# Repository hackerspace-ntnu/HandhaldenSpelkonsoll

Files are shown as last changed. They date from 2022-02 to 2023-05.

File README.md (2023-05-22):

# Handhalden Spelkonsoll
  
Dette er et prosjekt med mål om å utvikle en håndholdt spillkonsoll basert på ESP32 og skjermkontrolleren ILI9488.  
Spillkonsollen kommer med et egetutviklet snake-spill.
  
# Features som er planlagt og i utvikling:  
#### Hardware:  
* mikrokontroller: ESP32 dev board
* skjerm: ILI9488 480*320, 3.5"  
* input: Dpad + 4 knapper
* kretskort: [custom KiCad modell](hardware/kretskort/)  
* kabinett: 3d printet, [cad filer](hardware/design/) følger og det er åpent for tilpassing som i valg av farger

#### Software:  
* Spill: snake  
* Grafikk: [LVGL](https://github.com/lvgl/lvgl)
* ~~Kommunikasjonsprotokoll: [ESP-NOW](https://github.com/espressif/esp-now)~~

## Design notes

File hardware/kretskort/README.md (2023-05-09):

# kretskort

## TODO
- [ ] Fikse pull-up/down resistor (ikke ha en wack kombo av begge)
- [ ] Snu ESP-en, så usben ikke krasjer med resistorene
- [ ] Fjerne de knappene vi ikke trenger/ikke kan ha, pin 5-12 var muligens problematisk, flere kan også være det
- [ ] Finne riktige pins til skjermen
- [ ] Route på nytt

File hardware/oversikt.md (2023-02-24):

## Hardware (endringer kan forekomme)
* MCU: ESP32 
* Skjerm: ILI9488 480*320, 3.5"
* Knapper: Dpad + 4  
* Batteri: 18650 Li-ion (3.6 V, 2600 mAh)

## Koblinger mellom ILI9488 og ESP32
|ILI9488 | ESP32 | Notes: |
|---|---|---|
| SDO(MISO) |  19 | Master In Slave Out|
| SDO(MOSI) |  23 | Master out Slave In|
| SCK |  18 | Clock Signal | 
| CS |  16 | Chip Select |
| DC/RS |  17 | Data Command | 
| RST | 4 | Reset |
| VCC |  5V | Or 3.3V |
| LED |  5V | Or 3.3V |
| GND |  GND  | Ground |

## Koblinger mellom knapper og ESP32
| Knapp | ESP32 |
|---|---|
| BTN_A |  21 | 
| BTN_B |  32 |
| BTN_X |  33 |
| BTN_Y |  25 |
| BTN_DP_LEFT  |  14 | 
| BTN_DP_RIGHT |  13 | 
| BTN_DP_UP |  26 | 
| BTN_DP_DOWN  |  27 |

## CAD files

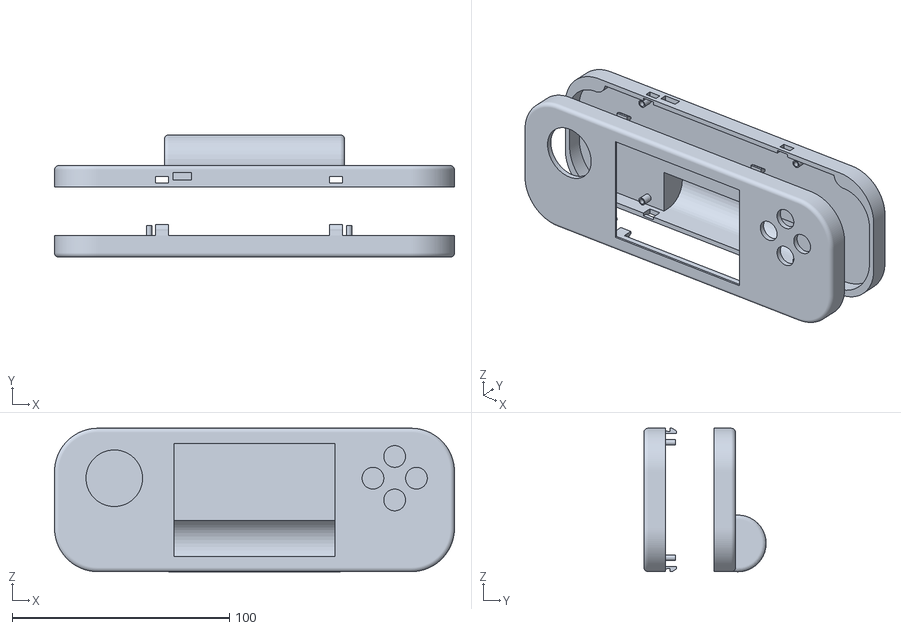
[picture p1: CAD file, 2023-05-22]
hardware/design/spillkonsoll_case.stl
184.0 x 56.3 x 66.0

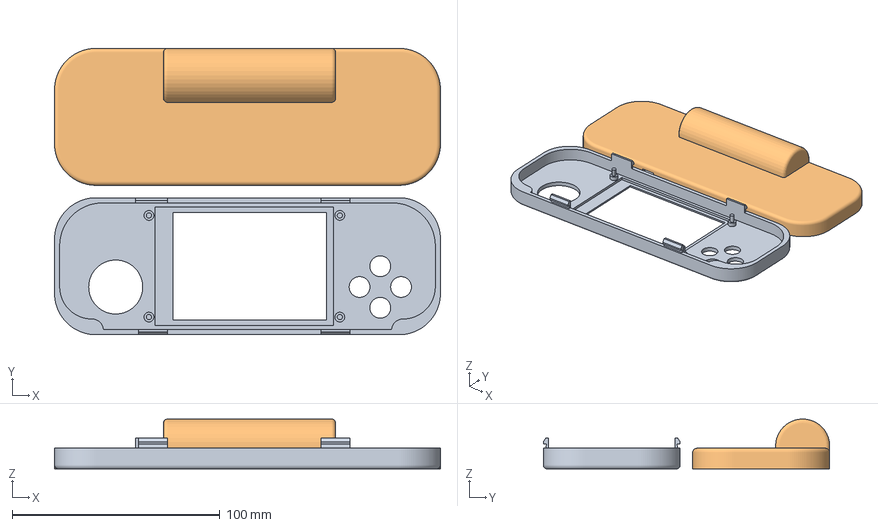
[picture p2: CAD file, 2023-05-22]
hardware/design/spillkonsoll_case_v3.3mf
186.0 x 138.0 x 24.1 mm
spillkonsoll_case_v3.stl_1
spillkonsoll_case_v3.stl_2

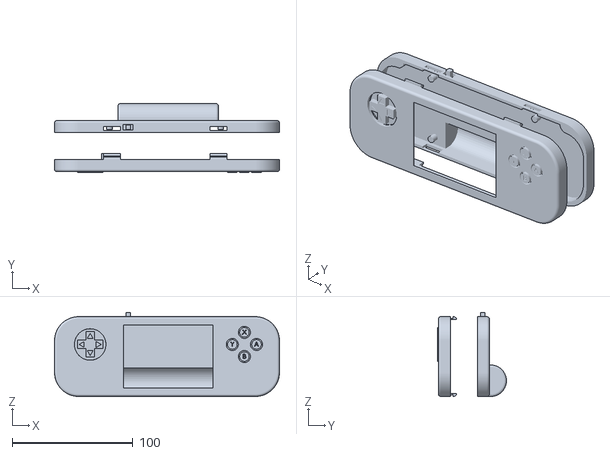
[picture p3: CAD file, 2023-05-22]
hardware/design/spillkonsoll_case_buttons.stl
186.0 x 57.0 x 69.5

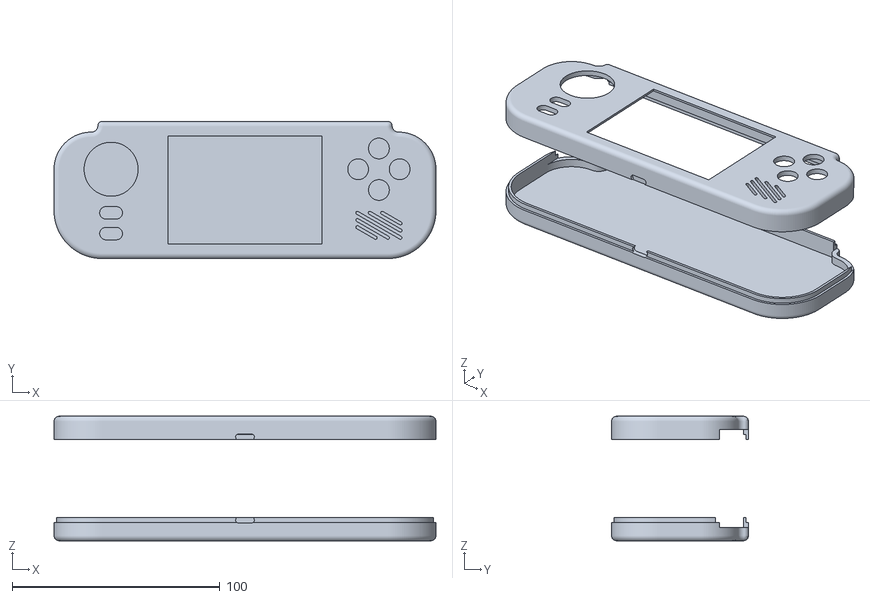
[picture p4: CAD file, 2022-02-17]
hardware/design/HandhaldenSpelkonsoll_1-1-3.stl
184.0 x 66.0 x 60.0

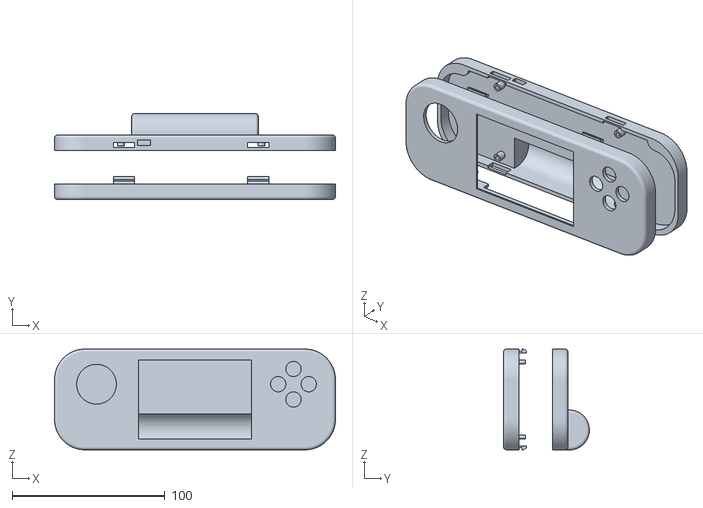
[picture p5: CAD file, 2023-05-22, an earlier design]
hardware/design/spillkonsoll_case_v2.stl
184.0 x 56.3 x 66.0

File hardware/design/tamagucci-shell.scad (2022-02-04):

// import("file.svg");

frontShell();

module frontShell() {
    difference() {
        frontShellWithoutHoles();
        frontHoles();
    }
}



module frontShellWithoutHoles() {
    difference() {
        union(){
            linear_extrude(15){
                translate([0, 0, 0]) {
                    square(size=[150, 70], center=true);
                }
            }
        }
        v = 2; 
        union(){
            translate([v/2, v/2, 0.1]) {
            linear_extrude(15){
                    square(size=[150-v*2, 70-v*2], center=true);
                }
            }
        }
    }
}

module frontHoles() {
    translate([0, 0, -0.1]) {
        linear_extrude(10){
            color([0/255, 0/255, 0/255]) {
                dpadHole(60,15);
                ssButtonHole(60,-20);
                gameButtonHole(-60,10);
                speakerHoles(-60,-20);
                screenHole();
            }
        }
    }
}

module hsLogo(x,y) {
    translate([x, y, 0]) {
        linear_extrude(height=10, center=true, convexity=10, twist=0) {
        import("Icon_green_transparent.svg");
        }
    }
}

module dpadHole(xPos,yPos) {
    d = 20;    //not acurate number 
    
    translate([xPos, yPos, 0]) {
        circle(r=d/2);
    }
}

module ssButtonHole(x,y) {

    x = x-2; //just to prettify. is bad code.

    d=6;  //depth
    w=10;  //heigth

    xDist = 0; // dist between buttons.
    yDist = 8;

    translate([x, y, 0]) {
        union(){
            circle(r=d/2, $fn=20);
            translate([w-d, 0, 0]) {
                circle(r=d/2, $fn=20);
            }
            translate([w/2 - d/2, 0, 0]) {
                square(size=[w-d, d], center=true);
            }
        }
    }
    translate([x+xDist, y+yDist, 0]) {
        union(){
            circle(r=d/2, $fn=20);
            translate([w-d, 0, 0]) {
                circle(r=d/2, $fn=20);
            }
            translate([w/2 - d/2, 0, 0]) {
                square(size=[w-d, d], center=true);
            }
        }
    }



}

module speakerHoles(xPos,yPos) {

    d=1; //diameter of lines
    l = 20; //mex length of diagonale in lines
    r = 37; //positive verdier.

    
    translate([xPos, yPos, 0]) {

        rotate([0, 0, r]) {
            union(){
                
                speakerHOleLine(d,l);
                //not geometrically parametric
                per = 0.7;
                translate([-cos(r), sin(r)+2*d, 0]) 
                    speakerHOleLine(d,l*per);
                translate([+cos(r), -sin(r)-2*d, 0]) 
                    speakerHOleLine(d,l*per);
                per2 = 0.4;
                translate([-2*cos(r), 2*sin(r)+4*d, 0]) 
                    speakerHOleLine(d,l*per2);
                translate([2*cos(r), -2*sin(r)-4*d, 0]) 
                    speakerHOleLine(d,l*per2);
                

            }
        }
    }
}
module speakerHOleLine(d,l) {
        union(){
            translate([(-l+d)/2, 0, 0]) {
            circle(r=d/2, $fn=15);
            }
            translate([(l-d)/2, 0, 0]) {
                circle(r=d/2, $fn=15);
            }
            square(size=[l-d, d], center=true);
        }
    
}



module gameButtonHole(xPos,yPos) {
    d = 10;     //not acurate number //diameter

    xDist = 15;  //not acurate number
    yDist = 20;  //not acurate number

    res = 30; //resolution of circle (polygon count)

    // translate([xPos, yPos, 0]) {
    //     circle(r=2); //centre pos
    // }
    translate([xPos+xDist/2, yPos, 0]) {
        circle(r=d/2 , $fn=res); //a
    }
    translate([xPos-xDist/2, yPos, 0]) {
        circle(r=d/2 , $fn=res); //y
    }
    translate([xPos, yPos+yDist/2, 0]) {
        circle(r=d/2 , $fn=res); //x
    }
    translate([xPos, yPos-yDist/2, 0]) {
        circle(r=d/2 , $fn=res); //b
    }
}

module screenHole() {
    wScreen = 85;
    hScreen = 56;
    //skjerm
    square(size=[wScreen, hScreen], center=true);
}

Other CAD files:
hardware/design/knapper.blend
hardware/design/spillkonsoll_case.blend
hardware/design/spillkonsoll_case_old.blend
hardware/design/spillkonsoll_case_v3.stl

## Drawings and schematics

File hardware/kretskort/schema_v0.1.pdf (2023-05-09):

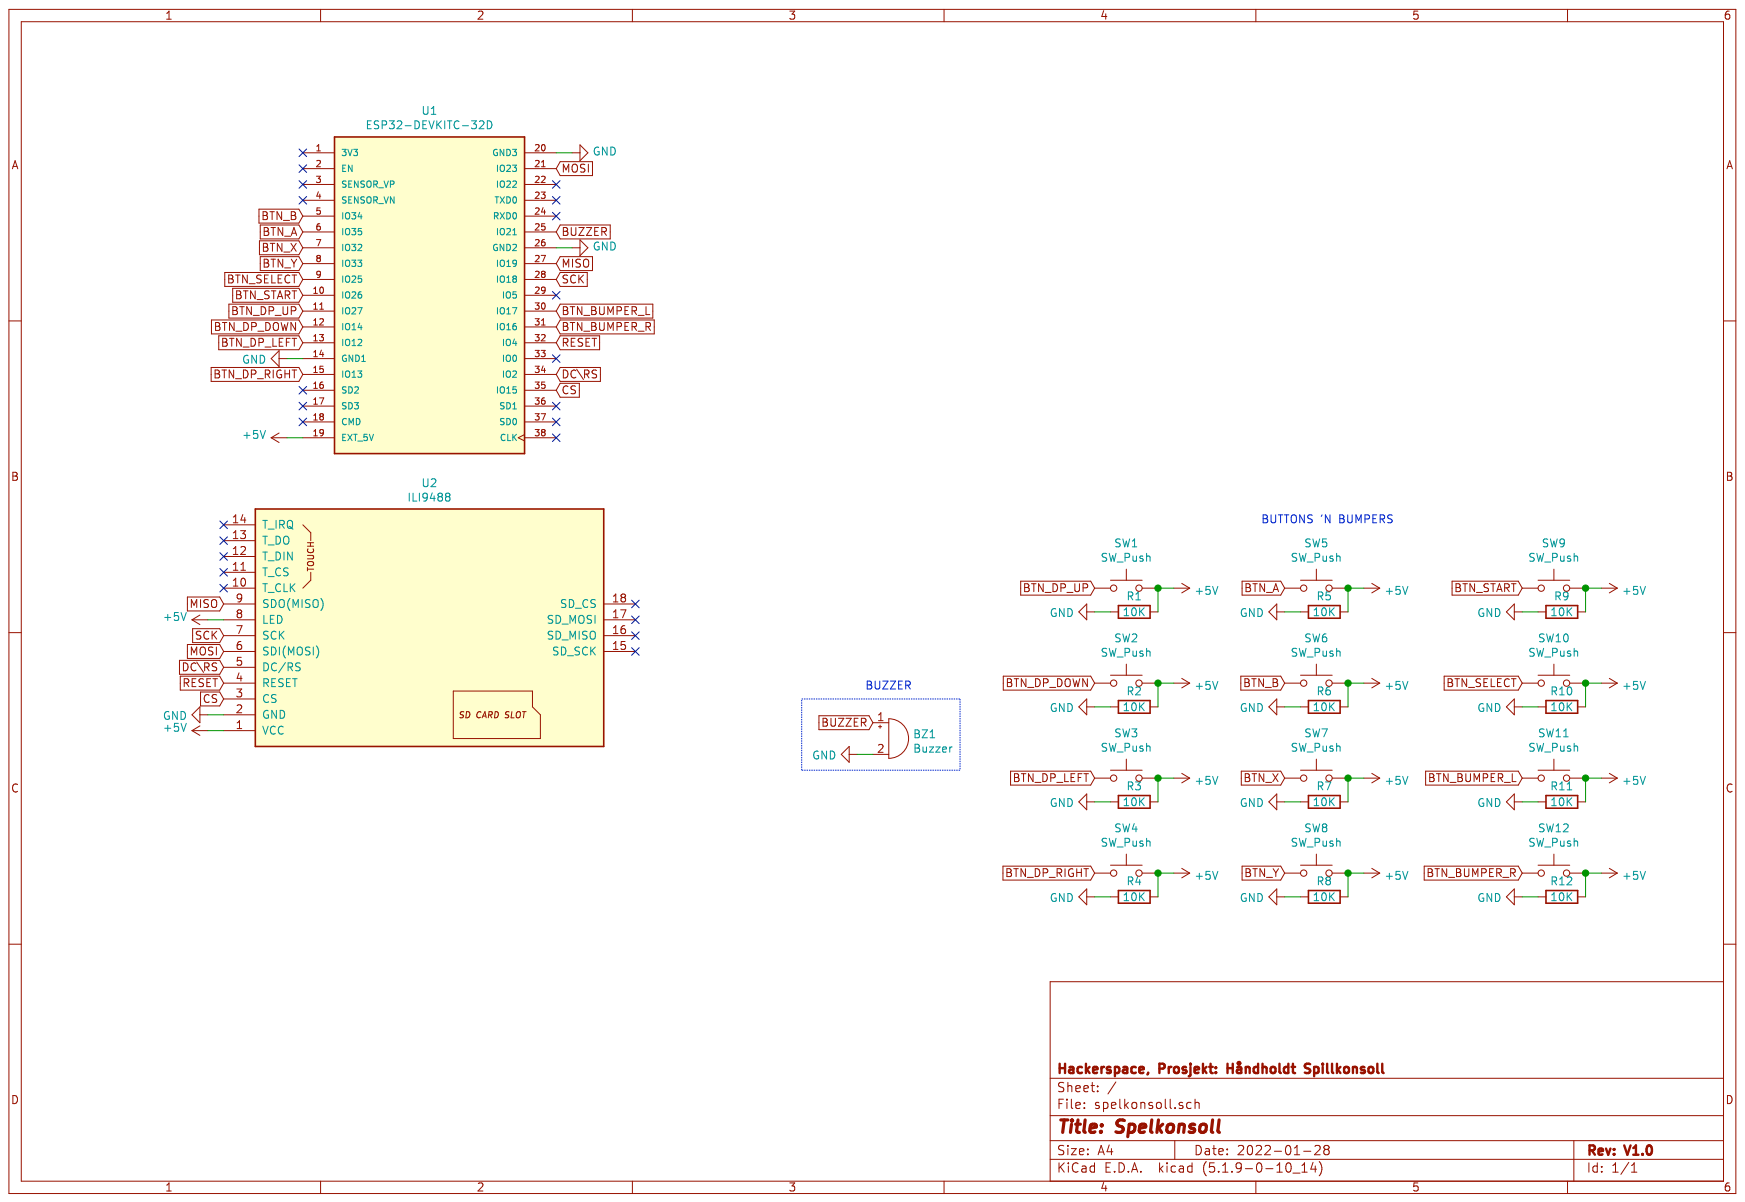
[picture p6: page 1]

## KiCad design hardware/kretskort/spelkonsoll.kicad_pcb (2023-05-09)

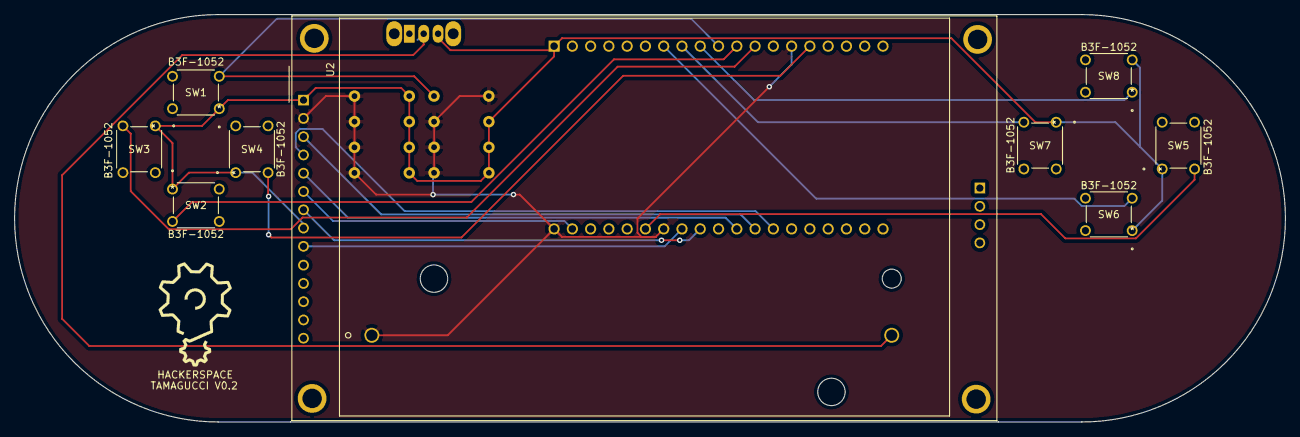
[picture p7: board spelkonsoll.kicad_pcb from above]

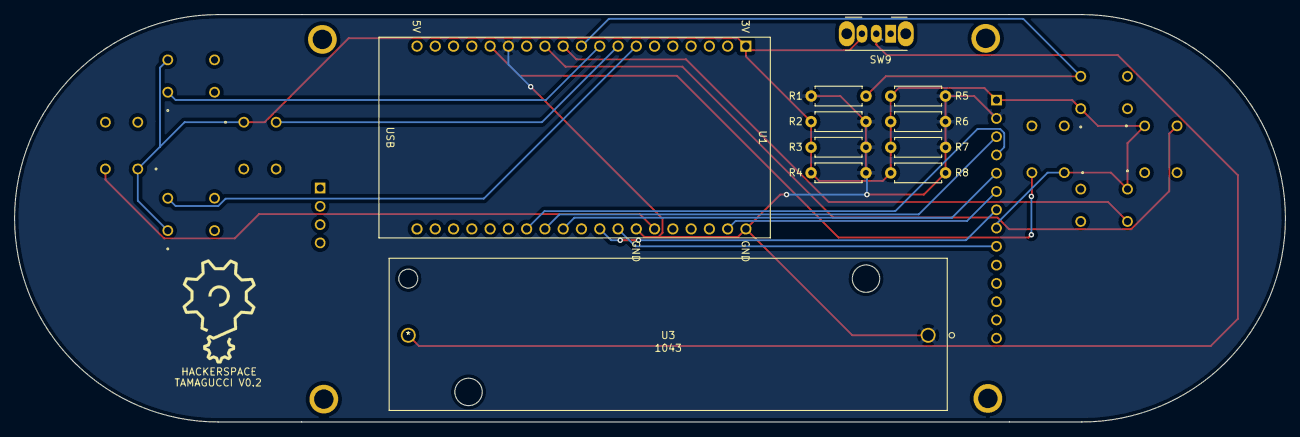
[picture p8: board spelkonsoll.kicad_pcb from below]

Board: 2 copper layers, 176.6 x 56.6 mm, 20 parts (11 on the bottom side), 17 nets.

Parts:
R1, R2, R3, R4, R5, R6, R7, R8: 10K; R_Axial_DIN0207_L6.3mm_D2.5mm_P7.62mm_Horizontal
SW1, SW2, SW3, SW4, SW5, SW6, SW7, SW8: B3F-1052; Button
SW9: SW_DPDT_x2; PowerButton
U1: ESP32-DEVKITC-32D; MODULE_ESP32-DEVKITC-32D
U2: ILI9488
U3: 1043; 18650holder

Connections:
+5V: R2.1, R3.1, R4.1, R5.1, R6.1, R7.1, R8.1, SW1.1, SW2.1, SW3.1, SW4.1, SW5.1, SW6.1, SW7.1, SW8.3, SW9.3, U1.1, U2.1, U2.8
BTN_A: SW5.3, U1.25
BTN_B: SW6.3, U1.7
BTN_DP_DOWN: SW2.3, U1.11
BTN_DP_LEFT: SW3.3, U1.12
BTN_DP_RIGHT: SW4.3, U1.15
BTN_DP_UP: R1.1, SW1.3, U1.10
BTN_X: SW7.3, U1.8
BTN_Y: SW8.1, U1.9
CS: U1.31, U2.3
DC\RS: U1.30, U2.5
GND: R1.2, R2.2, R3.2, R4.2, R5.2, R6.2, R7.2, R8.2, U1.14, U1.20, U1.26, U2.2, U3.1
MISO: U1.27, U2.9
MOSI: U1.21, U2.6
unnamed: SW9.2, U3.2
RESET: U1.32, U2.4
SCK: U1.28, U2.7

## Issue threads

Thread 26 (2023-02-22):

Memory error in create_snake

Joakim-droid, 2023-02-22:
During a graphics-test, I discovered that when creating a snake the ESP32 keeps resetting itself because of a memory-error. Following the stack-trace the problem occurs at line 10 and 13 in push() in snake.c, where memory is allocated for the new part and new coordinates is set. I suspect the coordinates is wrong somehow, but it could also be that it fails to allocate memory.

Joakim-droid, 2023-04-22:
Fixed

Closed 2023-04-22.

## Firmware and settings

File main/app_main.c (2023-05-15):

#include "board.h"
#include "snake.h"
#include "button.h"
#include "lvgl.h"
#include "lvgl_helpers.h"
#include "esp_freertos_hooks.h"
#include "freertos/semphr.h"
#include "esp_system.h"
#include "esp_timer.h"
#include "esp_heap_caps.h"
#include "driver/gpio.h"


#define LV_TICK_PERIOD_MS 1

board_piece_t* p_board;
snake_t test_snake;
int tick = 0;
int snake_count = 0;
int food_count=0;



lv_obj_t* brd_lv_obj_t[BOARD_HEIGHT*BOARD_WIDTH];
lv_obj_t* bkgrnd;
lv_obj_t* block_food;

static board_piece_t board[BOARD_HEIGHT * BOARD_WIDTH];
board_piece_t* p_board = &board[0];

static void lv_tick_task(void *arg);
static void guiTask(void *pvParameter);
void draw_board(board_piece_t* p);

lv_color_t* buf1;
lv_color_t* buf2;
SemaphoreHandle_t xGuiSemaphore;
int direction=0;

gpio_num_t button_pins[4] = {BTN_DP_UP, BTN_B, BTN_DP_RIGHT,BTN_A};

lv_style_t style_snake;
lv_style_t style_blank;
lv_style_t style_food;

void init_buttons() {
    for(int i=0; i<4; i++){
        gpio_set_direction(button_pins[i], GPIO_MODE_INPUT);
    }
}

int read_button(gpio_num_t pin) {
    return gpio_get_level(pin);
}

void app_main(void){

    int tick = 0;
    int count_food = 0;
    int do_movement = 1;
    int snake_id_counter = 0;
    
    init_buttons();

    snake_t snake1;
    snake_t snake2;

    int init_coordinates1[][2] = {{0, 0}, {1, 0}, {2, 0}}; 
    int init_coordinates2[][2] = {{BOARD_WIDTH-0, BOARD_HEIGHT-1}, {BOARD_WIDTH-2, BOARD_HEIGHT-1}, {BOARD_WIDTH-3, BOARD_HEIGHT-1}}; 
    init_board(p_board);

    switch (PLAYER_NUMBER){
        case 1:
            // Middle of the board
            init_coordinates1[0][0] = (BOARD_WIDTH/2); 
            init_coordinates1[1][0] = (BOARD_WIDTH/2)+1; 
            init_coordinates1[2][0] = (BOARD_WIDTH/2)+2; 
            init_coordinates1[0][1] = BOARD_HEIGHT/2+1; 
            init_coordinates1[1][1] = BOARD_HEIGHT/2+1; 
            init_coordinates1[2][1] = BOARD_HEIGHT/2+1; 

            test_snake = create_snake(p_board, 3, init_coordinates1, &snake_id_counter);
            add_snake_to_board(p_board, test_snake.head);

            //initial food
            place_random_food(p_board, &count_food); 
            break;

        case 2:
            snake1 = create_snake(p_board, 3, init_coordinates1, &snake_id_counter);
            snake2 = create_snake(p_board, 3, init_coordinates2, &snake_id_counter);
            add_snake_to_board(p_board, snake1.head);
            add_snake_to_board(p_board, snake2.head);

            //initial food
            place_random_food(p_board, &count_food);
            break;
        
        default:
            break;
    }
    
    lv_init();
    esp_timer_init();
    /* Initialize SPI bus used by the drivers */
    lvgl_driver_init();
    /* Use double buffered when not working with monochrome displays */
    buf1 = heap_caps_malloc(DISP_BUF_SIZE * sizeof(lv_color_t), MALLOC_CAP_DMA);
    buf2 = heap_caps_malloc(DISP_BUF_SIZE * sizeof(lv_color_t), MALLOC_CAP_DMA);
    assert(buf1 != NULL);
    assert(buf2 != NULL);
    static lv_disp_buf_t disp_buf;
    lv_disp_buf_init(&disp_buf, buf1, buf2, DISP_BUF_SIZE); /*Initialize `disp_buf` with the buffer(s) */
    lv_disp_drv_t disp_drv; /*A variable to hold the drivers. Can be local variable*/
    lv_disp_drv_init(&disp_drv); /*Basic initialization*/
    disp_drv.flush_cb = disp_driver_flush; /*Set a flush callback to draw to the display*/
    disp_drv.buffer = &disp_buf; /*Set an initialized buffer*/
    lv_disp_drv_register(&disp_drv); /*Register the driver and save the created display objects*/
    /* Create and start a periodic timer interrupt to call lv_tick_inc */
    const esp_timer_create_args_t periodic_timer_args = {
        .callback = &lv_tick_task,
        .name = "periodic_gui"
    };
    esp_timer_handle_t periodic_timer;
    ESP_ERROR_CHECK(esp_timer_create(&periodic_timer_args, &periodic_timer));
    ESP_ERROR_CHECK(esp_timer_start_periodic(periodic_timer, LV_TICK_PERIOD_MS * 400));
    
    bkgrnd = lv_obj_create(lv_scr_act(), NULL);
    lv_obj_set_width(bkgrnd, SCREEN_WIDTH);
    lv_obj_set_height(bkgrnd, SCREEN_HEIGHT);
    lv_obj_set_style_local_bg_color(bkgrnd, LV_OBJ_PART_MAIN, LV_STATE_DISABLED, LV_COLOR_WHITE);
    _lv_obj_set_style_local_color(bkgrnd, LV_OBJ_PART_MAIN, LV_STATE_DISABLED, LV_COLOR_WHITE);

    lv_style_init(&style_snake);
    lv_style_init(&style_blank);
    lv_style_init(&style_food);
    lv_style_set_bg_color(&style_snake, LV_STATE_DEFAULT, LV_COLOR_GREEN);
    
    lv_style_set_bg_color(&style_blank, LV_STATE_DISABLED, LV_COLOR_WHITE);
    lv_style_set_line_color(&style_blank, LV_STATE_DISABLED, LV_COLOR_WHITE);
    lv_style_set_border_color(&style_blank, LV_STATE_DISABLED, LV_COLOR_WHITE);
    lv_style_set_bg_grad_color(&style_blank, LV_STATE_DISABLED, LV_COLOR_WHITE);
    
    lv_style_set_bg_color(&style_food,LV_STATE_DEFAULT, LV_COLOR_RED);

    block_food = lv_obj_create(bkgrnd, NULL);
    lv_obj_add_style(block_food, LV_OBJ_PART_MAIN, &style_food);
    lv_obj_set_height(block_food, BLOCK_SIZE);
    lv_obj_set_width(block_food, BLOCK_SIZE);
    lv_obj_move_foreground(block_food);
    lv_obj_set_top(block_food, true);
    
    for (int i = 0; i < BOARD_HEIGHT; i++) {
        printf("\n");
        for (int j = 0; j < BOARD_WIDTH; j++) {
            board_piece_t temp = get_square_value(p_board, j, i);
            // short int temp = p_board[0].piece_type;
            brd_lv_obj_t[i*j] = lv_obj_create(bkgrnd, NULL);
            lv_obj_add_style(brd_lv_obj_t[i*j], LV_OBJ_PART_MAIN, &style_blank);
            lv_obj_set_width(brd_lv_obj_t[i*j], SCREEN_WIDTH);
            lv_obj_set_height(brd_lv_obj_t[i*j], SCREEN_HEIGHT);
            lv_obj_move_background(brd_lv_obj_t[i*j]);
            
            
            if (temp.piece_type == BLOCK_SNAKE) {
                 lv_obj_add_style(brd_lv_obj_t[snake_count], LV_OBJ_PART_MAIN, &style_snake);
                // lv_obj_set_style_local_bg_color(brd_lv_obj_t[i*j], LV_OBJ_PART_MAIN, LV_STATE_DEFAULT, LV_COLOR_BLUE);
                lv_obj_set_x(brd_lv_obj_t[snake_count], j*BLOCK_SIZE);
                lv_obj_set_y(brd_lv_obj_t[snake_count], i*BLOCK_SIZE);
                lv_obj_set_height(brd_lv_obj_t[snake_count], BLOCK_SIZE);
                lv_obj_set_width(brd_lv_obj_t[snake_count], BLOCK_SIZE);
                lv_obj_move_foreground(brd_lv_obj_t[snake_count]);
                lv_obj_set_top(brd_lv_obj_t[snake_count], true);


                printf("s");
                snake_count++; 
            }
            else if (temp.piece_type == BLOCK_FOOD) {
                lv_obj_set_x(block_food, j*BLOCK_SIZE);
                lv_obj_set_y(block_food, i*BLOCK_SIZE);

                printf("f");
            } else if (temp.piece_type == BLOCK_BLANK) {
                lv_obj_add_style(brd_lv_obj_t[i*j]  , LV_BTN_PART_MAIN, &style_blank);
                printf("#");
            }
        }
    }



    snake_count=0;

    while (1) { 
        vTaskDelay(pdMS_TO_TICKS(500));

        printf("\n");

        for(int i=0; i<4; i++){
            printf("%d", read_button(button_pins[i]));
        }

        printf("\n");

        if (read_button(button_pins[0])==1) {
            set_direction(&test_snake, DIRECTION_UP);
        }
        if (read_button(button_pins[1])==1) {
            set_direction(&test_snake, DIRECTION_RIGHT);
        }
        if (read_button(button_pins[2])==1) {
            set_direction(&test_snake, DIRECTION_DOWN);
        }
        if (read_button(button_pins[3])==1) {
            set_direction(&test_snake, DIRECTION_LEFT);
        }

        if(do_movement){ //Should be set to 1 every second
            move(p_board, &test_snake, &test_snake.head, test_snake.direction_x, test_snake.direction_y, &count_food);
            print_board(p_board);  
            // printf(count_food);
            // printf("%d",count_food);
            count_food=0;
        }

        snake_count=0;
        food_count=0;

        for (int i = 0; i < BOARD_HEIGHT; i++) {
            printf("\n");

            for (int j = 0; j < BOARD_WIDTH; j++) {
                board_piece_t temp = get_square_value(p_board, j, i);

                if (temp.piece_type == BLOCK_SNAKE) {
                    lv_obj_invalidate(brd_lv_obj_t[snake_count]);
                    lv_obj_add_style(brd_lv_obj_t[snake_count], LV_OBJ_PART_MAIN, &style_snake);
                    lv_obj_set_x(brd_lv_obj_t[snake_count], j*BLOCK_SIZE);
                    lv_obj_set_y(brd_lv_obj_t[snake_count], i*BLOCK_SIZE);
                    lv_obj_set_height(brd_lv_obj_t[snake_count], BLOCK_SIZE);
                    lv_obj_set_width(brd_lv_obj_t[snake_count], BLOCK_SIZE);
                    lv_obj_move_foreground(brd_lv_obj_t[snake_count]);
                    lv_obj_set_top(brd_lv_obj_t[snake_count], true);
                    printf("s");
                    snake_count++; 
                } else if (temp.piece_type == BLOCK_FOOD) {
                    if (test_snake.isAlive==true) {
                        lv_obj_invalidate(block_food);
                        lv_obj_set_x(block_food, j*BLOCK_SIZE);
                        lv_obj_set_y(block_food, i*BLOCK_SIZE);
                        lv_obj_move_foreground(block_food);
                        lv_obj_set_top(block_food, true);
                    } else {
                        printf("dead");
                        lv_obj_invalidate(brd_lv_obj_t[food_count]);
                        lv_obj_add_style(brd_lv_obj_t[food_count], LV_OBJ_PART_MAIN, &style_food);
                        lv_obj_set_x(brd_lv_obj_t[food_count], j*BLOCK_SIZE);
                        lv_obj_set_y(brd_lv_obj_t[food_count], i*BLOCK_SIZE);
                        lv_obj_set_height(brd_lv_obj_t[food_count], BLOCK_SIZE);
                        lv_obj_set_width(brd_lv_obj_t[food_count], BLOCK_SIZE);
                        lv_obj_move_foreground(brd_lv_obj_t[food_count]);
                        lv_obj_set_top(brd_lv_obj_t[food_count], true);
                        food_count++;
                    }

                   printf("f");
                }
                           }
        }
        printf("\n");

        lv_task_handler();
    }
}


static void lv_tick_task(void *arg) {
    (void) arg;

    lv_tick_inc(LV_TICK_PERIOD_MS);
}

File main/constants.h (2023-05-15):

#include <stdio.h>
#include <signal.h>
#include <unistd.h>
#include <stdlib.h>
#include <string.h>
#include <assert.h>
#include <inttypes.h>
#include <math.h>
#include <stdbool.h>
#include <stdint.h> 

#ifndef CONSTANTS_H
#define CONSTANTS_H

#define SCREEN_HEIGHT 320
#define SCREEN_WIDTH 480
#define BLOCK_SIZE 80

#define PLAYER_NUMBER 1 // Number of players in the game
#define MAX_FOOD_AT_ONCE 1 //Will be adjusted on amount of players later

#define MULTIPLAYER_BUFFER_SIZE 256
#define IS_HOST 1

#define BOARD_HEIGHT (SCREEN_HEIGHT/BLOCK_SIZE)
#define BOARD_WIDTH (SCREEN_WIDTH/BLOCK_SIZE)

#define BLOCK_BLANK 0
#define BLOCK_FOOD 1
#define BLOCK_SNAKE 2

#define WRAPPING_ENABLED 1

#define DIRECTION_UP 0
#define DIRECTION_RIGHT 1
#define DIRECTION_DOWN 2
#define DIRECTION_LEFT 3

#endif

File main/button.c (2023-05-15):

#include "button.h"

//void init_buttons() {
//    for(int i=0; i<8; i++){
//        gpio_set_direction(button_pins[i], GPIO_MODE_INPUT);
//    }
//}

//int read_button(gpio_num_t pin) {
//    return gpio_get_level(pin);
//}

/*
    ----------------------------------------------------------
    Nedenfor ligger et gpio-eksempel fra ESP-IDF
    Det er ønskelig å beholde denne koden for diverse grunner
    ----------------------------------------------------------
*/

/* GPIO Example
   This example code is in the Public Domain (or CC0 licensed, at your option.)
   Unless required by applicable law or agreed to in writing, this
   software is distributed on an "AS IS" BASIS, WITHOUT WARRANTIES OR
   CONDITIONS OF ANY KIND, either express or implied.
*/

/**
 * Brief:
 * This test code shows how to configure gpio and how to use gpio interrupt.
 *
 * GPIO status:
 * GPIO18: output (ESP32C2/ESP32H2/ESP32H4 uses GPIO8 as the second output pin)
 * GPIO19: output (ESP32C2/ESP32H2/ESP32H4 uses GPIO9 as the second output pin)
 * GPIO4:  input, pulled up, interrupt from rising edge and falling edge
 * GPIO5:  input, pulled up, interrupt from rising edge.
 *
 * Note. These are the default GPIO pins to be used in the example. You can
 * change IO pins in menuconfig.
 *
 * Test:
 * Connect GPIO18(8) with GPIO4
 * Connect GPIO19(9) with GPIO5
 * Generate pulses on GPIO18(8)/19(9), that triggers interrupt on GPIO4/5
 *
 */


/*
#define GPIO_OUTPUT_IO_0    GPIO_NUM_18
#define GPIO_OUTPUT_IO_1    GPIO_NUM_19
#define GPIO_OUTPUT_PIN_SEL  ((1ULL<<GPIO_OUTPUT_IO_0) | (1ULL<<GPIO_OUTPUT_IO_1))
#define GPIO_INPUT_IO_0     GPIO_NUM_4
#define GPIO_INPUT_IO_1     GPIO_NUM_5
#define GPIO_INPUT_PIN_SEL  ((1ULL<<GPIO_INPUT_IO_0) | (1ULL<<GPIO_INPUT_IO_1))
#define ESP_INTR_FLAG_DEFAULT 0

static QueueHandle_t gpio_evt_queue = NULL;

static void IRAM_ATTR gpio_isr_handler(void* arg) {
    uint32_t gpio_num = (uint32_t) arg;
    xQueueSendFromISR(gpio_evt_queue, &gpio_num, NULL);
}

static void gpio_task_example(void* arg) {
    uint32_t io_num;
    for(;;) {
        if(xQueueReceive(gpio_evt_queue, &io_num, portMAX_DELAY)) {
            printf("GPIO[%"PRIu32"] intr, val: %d\n", io_num, gpio_get_level(io_num));
        }
    }
}

void app_main(void) {
    //zero-initialize the config structure.
    gpio_config_t io_conf = {};
    //disable interrupt
    io_conf.intr_type = GPIO_INTR_DISABLE;
    //set as output mode
    io_conf.mode = GPIO_MODE_OUTPUT;
    //bit mask of the pins that you want to set,e.g.GPIO18/19
    io_conf.pin_bit_mask = GPIO_OUTPUT_PIN_SEL;
    //disable pull-down mode
    io_conf.pull_down_en = 0;
    //disable pull-up mode
    io_conf.pull_up_en = 0;
    //configure GPIO with the given settings
    gpio_config(&io_conf);

    //interrupt of rising edge
    io_conf.intr_type = GPIO_INTR_POSEDGE;
    //bit mask of the pins, use GPIO4/5 here
    io_conf.pin_bit_mask = GPIO_INPUT_PIN_SEL;
    //set as input mode
    io_conf.mode = GPIO_MODE_INPUT;
    //enable pull-up mode
    io_conf.pull_up_en = 1;
    gpio_config(&io_conf);

    //change gpio interrupt type for one pin
    gpio_set_intr_type(GPIO_INPUT_IO_0, GPIO_INTR_ANYEDGE);

    //create a queue to handle gpio event from isr
    gpio_evt_queue = xQueueCreate(10, sizeof(uint32_t));
    //start gpio task
    xTaskCreate(gpio_task_example, "gpio_task_example", 2048, NULL, 10, NULL);

    //install gpio isr service
    gpio_install_isr_service(ESP_INTR_FLAG_DEFAULT);
    //hook isr handler for specific gpio pin
    gpio_isr_handler_add(GPIO_INPUT_IO_0, gpio_isr_handler, (void*) GPIO_INPUT_IO_0);
    //hook isr handler for specific gpio pin
    gpio_isr_handler_add(GPIO_INPUT_IO_1, gpio_isr_handler, (void*) GPIO_INPUT_IO_1);

    //remove isr handler for gpio number.
    gpio_isr_handler_remove(GPIO_INPUT_IO_0);
    //hook isr handler for specific gpio pin again
    gpio_isr_handler_add(GPIO_INPUT_IO_0, gpio_isr_handler, (void*) GPIO_INPUT_IO_0);

    printf("Minimum free heap size: %"PRIu32" bytes\n", esp_get_minimum_free_heap_size());

    int cnt = 0;
    while(1) {
        printf("cnt: %d\n", cnt++);
        vTaskDelay(1000 / portTICK_PERIOD_MS);
        gpio_set_level(GPIO_OUTPUT_IO_0, cnt % 2);
        gpio_set_level(GPIO_OUTPUT_IO_1, cnt % 2);
    }
}

*/

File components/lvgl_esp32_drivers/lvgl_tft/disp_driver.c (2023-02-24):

/**
 * @file disp_driver.c
 */

#include "disp_driver.h"
#include "disp_spi.h"
#include "sdkconfig.h"

void *disp_driver_init(void)
{
#if defined CONFIG_LV_TFT_DISPLAY_CONTROLLER_ILI9488
    ili9488_init();
#endif

    // We still use menuconfig for these settings
    // It will be set up during runtime in the future
#if (defined(CONFIG_LV_DISP_BACKLIGHT_SWITCH) || defined(CONFIG_LV_DISP_BACKLIGHT_PWM))
    const disp_backlight_config_t bckl_config = {
        .gpio_num = CONFIG_LV_DISP_PIN_BCKL,
#if defined CONFIG_LV_DISP_BACKLIGHT_PWM
        .pwm_control = true,
#else
        .pwm_control = false,
#endif
#if defined CONFIG_LV_BACKLIGHT_ACTIVE_LVL
        .output_invert = false, // Backlight on high
#else
        .output_invert = true, // Backlight on low
#endif
        .timer_idx = 0,
        .channel_idx = 0 // @todo this prevents us from having two PWM controlled displays
    };
    disp_backlight_h bckl_handle = disp_backlight_new(&bckl_config);
    disp_backlight_set(bckl_handle, 100);
    return bckl_handle;
#else
    return NULL;
#endif
}

void disp_driver_flush(lv_disp_drv_t * drv, const lv_area_t * area, lv_color_t * color_map)
{
#if defined CONFIG_LV_TFT_DISPLAY_CONTROLLER_ILI9488
    ili9488_flush(drv, area, color_map);
#endif
}

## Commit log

2021-11-04 Made basic header file for board
2021-11-04 Created more board functions
2021-11-11 Created print board function, and cleaned up some code
2021-11-12 moved from Arduino IDE to VS Code
2021-11-13 included keypress code in board.c
2022-01-21 Did some fixes in movement code
    [constants.h]
2022-01-25 added design file
    a redesign in openscad
    [tamagucci-shell.scad]
2022-01-25 fix typo
    fixed a typo in line 69
    [tamagucci-shell.scad]
2022-01-28 New food will only appear if there is no other food on the board
2022-01-28 Can now add and control multiple snakes on one board
2022-02-04 circuit board kicad files
    [spelkonsoll.kicad_pcb, spelkonsoll.sch]
2022-02-04 added main body
    added the rest of holes and started work on the outer shell.
    [tamagucci-shell.scad]
2022-02-11 more circuit board kicad files
    [spelkonsoll.kicad_pcb, spelkonsoll.sch]
2022-02-17 added the stl file from deisgn group
    [HandhaldenSpelkonsoll_1-1-3.stl]
2022-02-17 modified pcb to fit new design
    [spelkonsoll.kicad_pcb, spelkonsoll.sch]
2022-02-17 fixed DRC error
    [spelkonsoll.kicad_pcb]
2022-02-25 Progress so far. Will crash :c
    [constants.h]
2022-02-25 added power circuit
    [spelkonsoll.kicad_pcb, spelkonsoll.sch]
2022-02-25 lol glemte å lagre
    [spelkonsoll.kicad_pcb, spelkonsoll.sch]
2022-03-04 Got rid of comments related to semafores and threads
2022-03-11 added pinouts between ILI9488 and ESP32
2022-03-16 la til gerber filer fra forrige gang
    [spelkonsoll-B_Cu.gbl, spelkonsoll-B_Mask.gbs, spelkonsoll-B_Paste.gbp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]
2022-03-16 modified buttons to maybe work
    [spelkonsoll.kicad_pcb, spelkonsoll.sch]
2022-03-16 lol glemte å lagre igjen
    [spelkonsoll.kicad_pcb]
2022-03-18 Snek can now commit die.
2022-03-23 Implemented out of bounds more tailored for current code condition
2022-03-25 -1 is now less than 0; i.e, implemented BoardPiece structs to keep piece types and body pointers
2022-03-26 added new gerber files
    [spelkonsoll-B_Cu.gbl, spelkonsoll-B_Mask.gbs, spelkonsoll-B_Paste.gbp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]
2022-03-26 added modified files for new circuit
    [spelkonsoll.sch]
2022-04-01 Added boundary checks for getting and setting board values
2022-04-22 started on v0.2 moved resistors and added silkscreen for inputs on the ESP32
    [spelkonsoll.kicad_pcb, spelkonsoll.sch]
2022-09-28 more header files corrections, now able to compile and upload to the esp32
2022-10-13 Added schema from v0.1, deleted buttons
    Moved resistors and deleted start, select, and shoulder buttons
    [spelkonsoll.kicad_pcb, spelkonsoll.sch]
2022-10-14 the slave prints out the mac-address of master
2022-10-27 added function to print MAC-address
2022-11-03 update KiCad files
    [spelkonsoll.kicad_pcb, spelkonsoll.sch]
2022-11-06 added button connections
2022-11-11 added folder for design related stuff
    [HandhaldenSpelkonsoll_1-1-3.stl, tamagucci-shell.scad]
2022-11-14 update schematic and footprints
    [spelkonsoll.kicad_pcb, spelkonsoll.sch]
2022-11-21 renamed old gerbers and added new symbols
2022-11-21 added power switch
    [spelkonsoll.kicad_pcb, spelkonsoll.sch]
2023-01-10 getting ready to switch from arduino to espressif
2023-01-21 removed arduino stuff, commented out some functions which could be useful later on.
2023-01-24 glemte å lagre :(
    [spelkonsoll.kicad_pcb, spelkonsoll.sch]
2023-01-25 added button files and tested it in the game loop
2023-01-28 going to try 1D array for the board
2023-01-29 må slutte å glemme å lagre :(
    [spelkonsoll.kicad_pcb, spelkonsoll.sch]
2023-01-31 adede lvgl and drivers
2023-02-04 deleted driver folder and moved all .h files into seperate folder
2023-02-08 added lvgl and drivers as a idf-component.
2023-02-08 slight changes in the drivers, deleted submodules
2023-02-09 moved lvgl into componentns folder
    [code-format.cfg]
2023-02-21 removed unused code, keeping some config for similar display drivers
2023-02-21 added default values in Kconfig and removed includes for drivers we don't have
2023-02-22 commented out printf because it interferes with the drawing, also removed som empty space in main
    [app_main.c]
2023-04-22 Working graphic for the first frame
2023-05-22 upload case files
    [knapper.blend, spillkonsoll_case.blend, spillkonsoll_case.stl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]

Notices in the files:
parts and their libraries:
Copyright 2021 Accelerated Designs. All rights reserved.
